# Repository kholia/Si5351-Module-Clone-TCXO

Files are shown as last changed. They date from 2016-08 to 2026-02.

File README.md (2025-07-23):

#### Notes

Note: We are using KiCad 7.0.x version to build this project.

[UPDATE] The design was validated on 27th-Feb-2023. It works really well for
WSPR @ 28 MHz where the original Adafruit Si5351 module is barely usable.

#### JLC PCBA files

- [Gerbers](./Adafruit-Si5351A-v3/jlcpcb/production_files/GERBER-Adafruit-Si5351A.zip)
- [BOM](./Adafruit-Si5351A-v3/jlcpcb/production_files/BOM-Adafruit-Si5351A.csv)
- [CPL](./Adafruit-Si5351A-v3/jlcpcb/production_files/CPL-Adafruit-Si5351A.csv)

#### PCB render

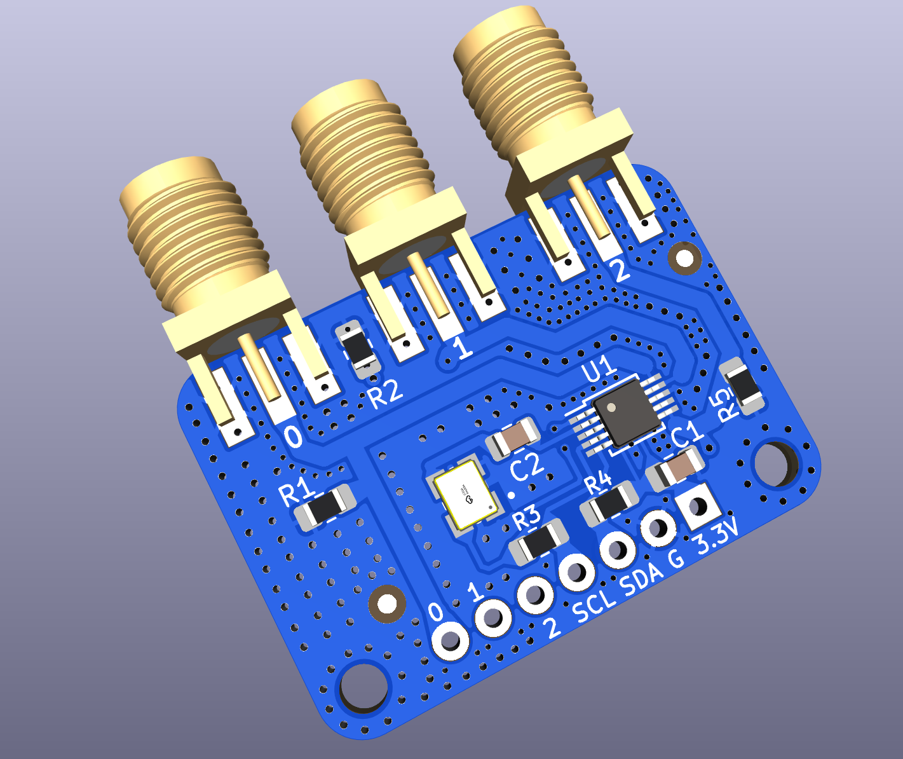
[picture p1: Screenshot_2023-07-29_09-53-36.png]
Render


#### BOM Sources

- https://www.lcsc.com/ - MS5351M

- https://www.comkey.in/ - SMD passives

- https://www.ktron.in/ - SMA connectors for cheap

- https://www.semikart.com/ - TCXOs

Note: International buyers can buy from DigiKey or Mouser.

#### Credits

- Sambhu Dharmadevan (VU3KQF)

- Dhiru Kholia (VU3CER)

#### Supported TCXO Modules

- [DEFAULT] KDS Daishinku 1XTW26000MAA (26 MHz)

- YXC Crystal Oscillators OW2EL89CENUXK7YLC-25M

- huaxindianzi 3T025000VX - 25 MHz

- Jauch Quartz O 25,0-JT32C-A-K-3,3-LF

- Abracon ASTX-H11-25.000MHZ-T

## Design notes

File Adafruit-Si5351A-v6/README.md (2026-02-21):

This version is ready for JLCPCB's PCBA process. Enjoy! ;)

This project uses KiCad 9.0.

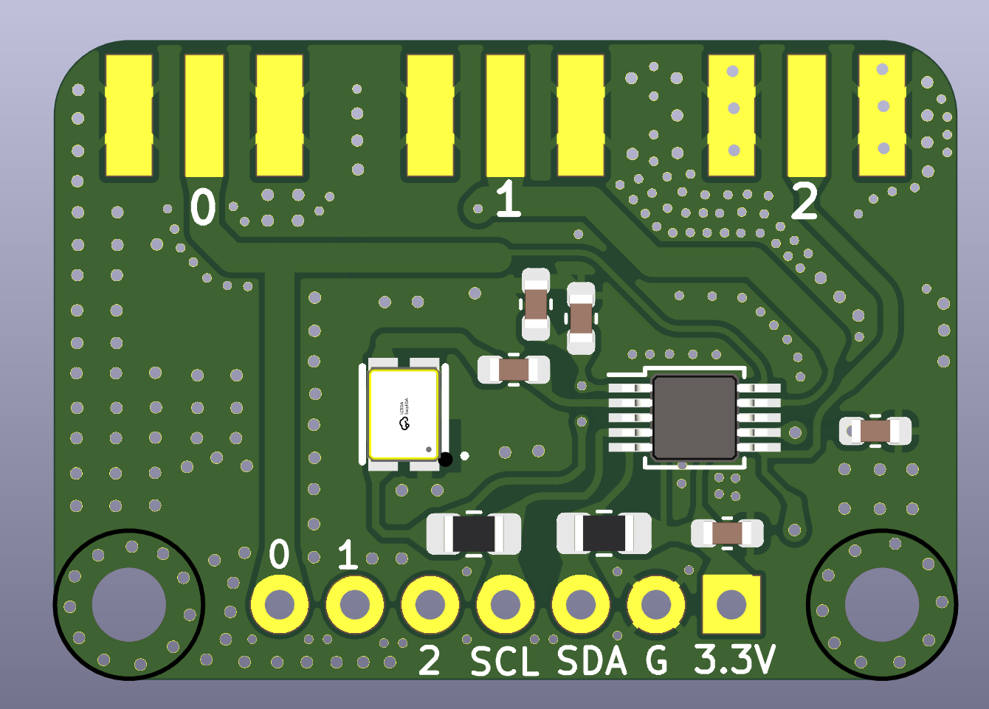
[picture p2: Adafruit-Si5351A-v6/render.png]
3D Render


Update (Feb-2026): These `Adafruit-Si5351A-v6` PCBs were assembled by JLCPCB and they work great!

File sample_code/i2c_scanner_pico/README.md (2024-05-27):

Si5351 chip will respond on the I2C bus even if it isn't connected to a clock
signal source (crystal / oscillator).

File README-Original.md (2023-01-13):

## Adafruit Si5351A Clock Generator Breakout PCB
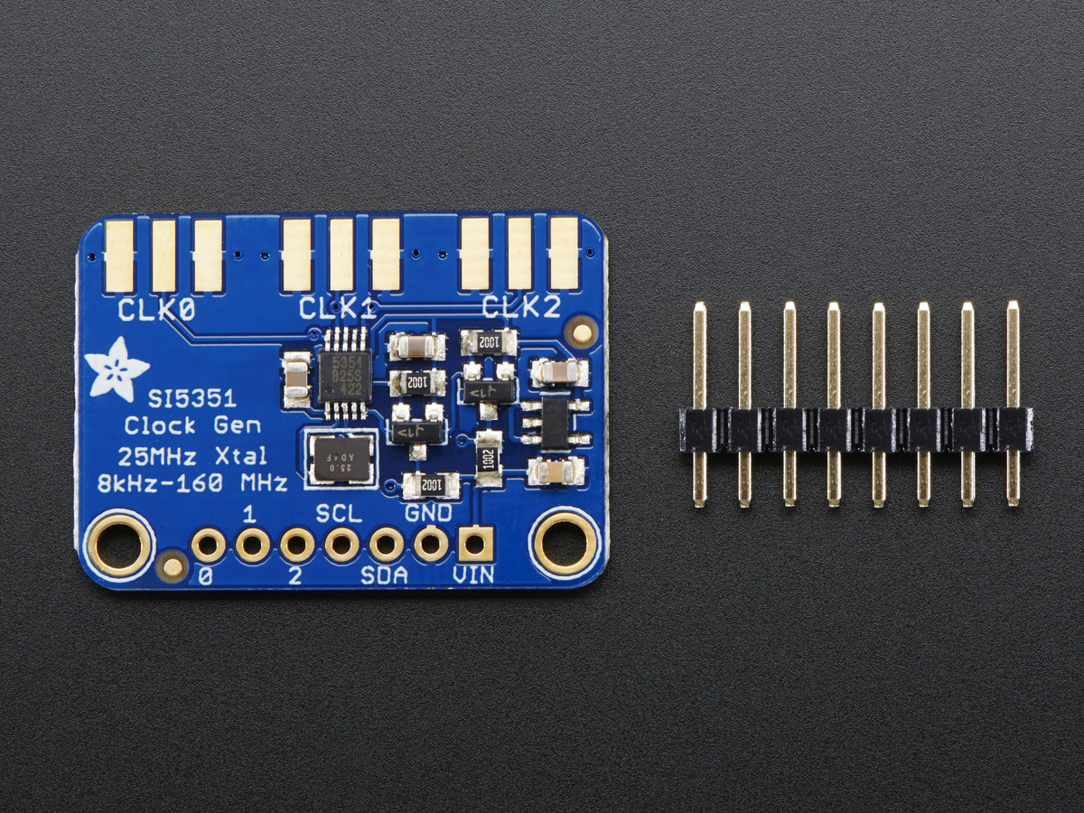
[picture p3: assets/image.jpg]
<a href="http://www.adafruit.com/products/2045"><br/>
Click here to purchase one from the Adafruit shop</a>

Never hunt around for another crystal again, with the Si5351A clock generator breakout from Adafruit! This chip has a precision 25MHz crystal reference and internal PLL and dividers so it can generate just about any frequency, from <8KHz up to 150+ MHz.

The Si5351A clock generator is an I2C controller clock generator. It uses the onboard precision clock to drive multiple PLL's and clock dividers using I2C instructions. By setting up the PLL and dividers you can create precise and arbitrary frequencies. There are three independent outputs, and each one can have a different frequency. Outputs are 3Vpp, either through a breadboard-friendly header or, for RF work, an optional SMA connector.

We put this handy little chip onto it's own breakout board PCB, with a 3.3V LDO regulator so it can be powered from 3-5VDC. We also put level shifting circuitry on the I2C lines so you can use this chip safely with 3V or 5V logic.

PCB files for the Adafruit Si5351A Clock Generator Breakout. The format is EagleCAD schematic and board layout
- http://www.adafruit.com/product/2045

### License

Adafruit invests time and resources providing this open source design, please support Adafruit and open-source hardware by purchasing products from [Adafruit](https://www.adafruit.com)!

All text above must be included in any redistribution

Designed by Limor Fried/Ladyada for Adafruit Industries.
Creative Commons Attribution/Share-Alike, all text above must be included in any redistribution.
See license.txt for additional information.

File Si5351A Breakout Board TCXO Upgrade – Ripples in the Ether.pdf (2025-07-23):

nt7s.com (https://nt7s.com/2016/04/si5351a-breakout-board-tcxo-upgrade/)

## Si5351A Breakout Board TCXO Upgrade – Ripples in the Ether

~3 minutes

Skip to content

I’m pleased to announce an upgrade to the Etherkit Si5351A Breakout Board with TCXO reference oscillator. In boards
manufactured previous to today (and the ones kitted in the initial crowdfunded initiative), the TCXO used was a Fox FOX924B-25.000. It worked well and did the job it was supposed to, but has one flaw in certain situations. The compensation loop in this particular TCXO has relatively wide frequency adjustment steps that can become obvious when using the Si5351A Breakout Board in a very narrow band mode such as QRSS. Here is a screen capture from Argo showing the behavior of the Si5351A Breakout Board with the Fox TCXO when outputting a carrier on 28 MHz, from a cold start.

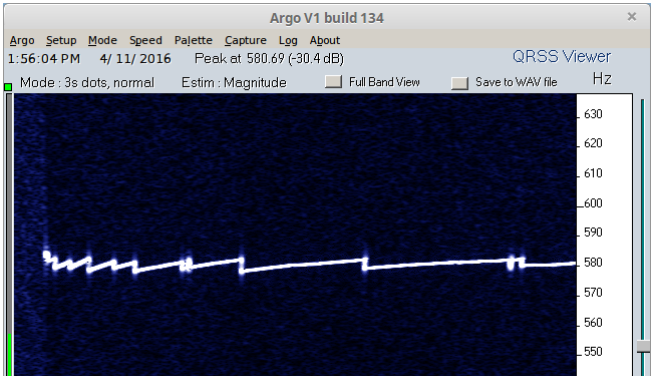
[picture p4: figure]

Fox FOX925B-25.000

As you can see, as the TCXO is stabilizing to operating temperature, the compensation circuit adjusts the frequency in relative course steps of around 3 Hz or so. Once the TCXO is warmed up, it jumps around less often, but still does occasionally have to frequency correct, and does so in a jump of similar size. This TCXO is still fine for most other uses, such as a VFO for a SSB/CW radio, but doesn’t work so great for the MEPT modes, especially on the upper frequency range of the Si5351.

In the course of developing OpenBeacon 2, I determined that I would need to find a more suitable TCXO to use with the Si5351. After trying about five different oscillators, I finally found a fantastic substitute, and it only costs a bit more than the Fox TCXO. The Abracon ASTX-H11-25.000MHZ-T comes in a smaller package than the
Fox FOX924B-25.000, but it will still fit on the footprint for X1 on the Si5351A Breakout Board. Here you can see the same test as above run for the Abracon TCXO.

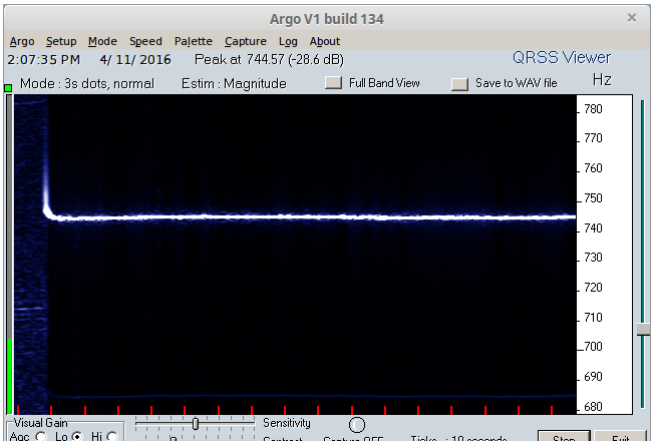
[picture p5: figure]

Abracon ASTX-H11-25.000M

It seems to find a stable frequency very quickly, and more importantly you can see that the compensation loop seems much tighter, with frequency corrections coming much faster and in smaller increments. You can only barely see a bit of fuzz from the frequency corrections on this low-bandwidth plot. This is much, much better for the MEPT modes.

As of today, all of the Si5351A Breakout Boards with TCXO option sold in the Etherkit store (https://www.etherkit.com/rf-modules/si5351a-breakout-board.html) will have the Abracon TCXO, and the price will stay the same at $15.

### Post navigation

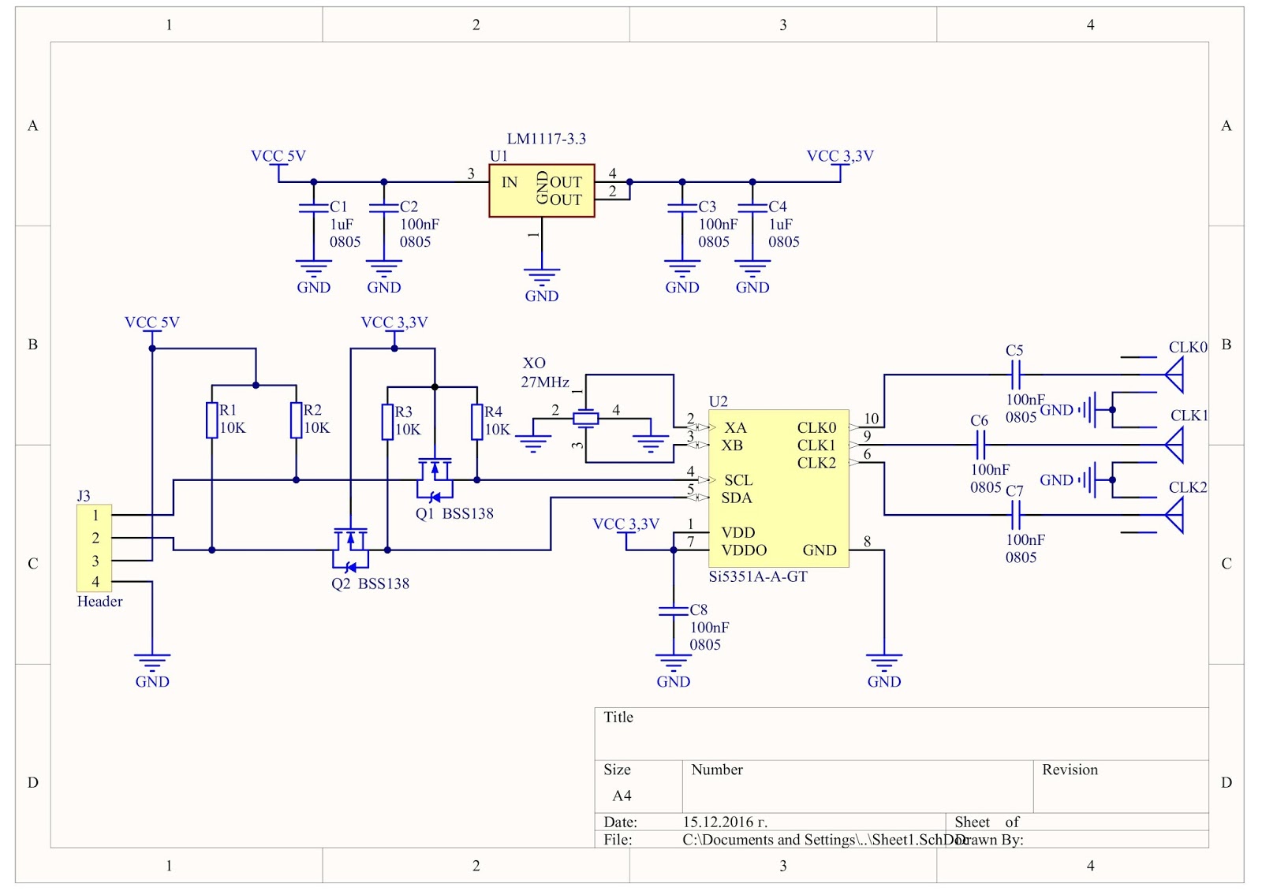
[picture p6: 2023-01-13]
datasheets/Schematic_Project1.jpg

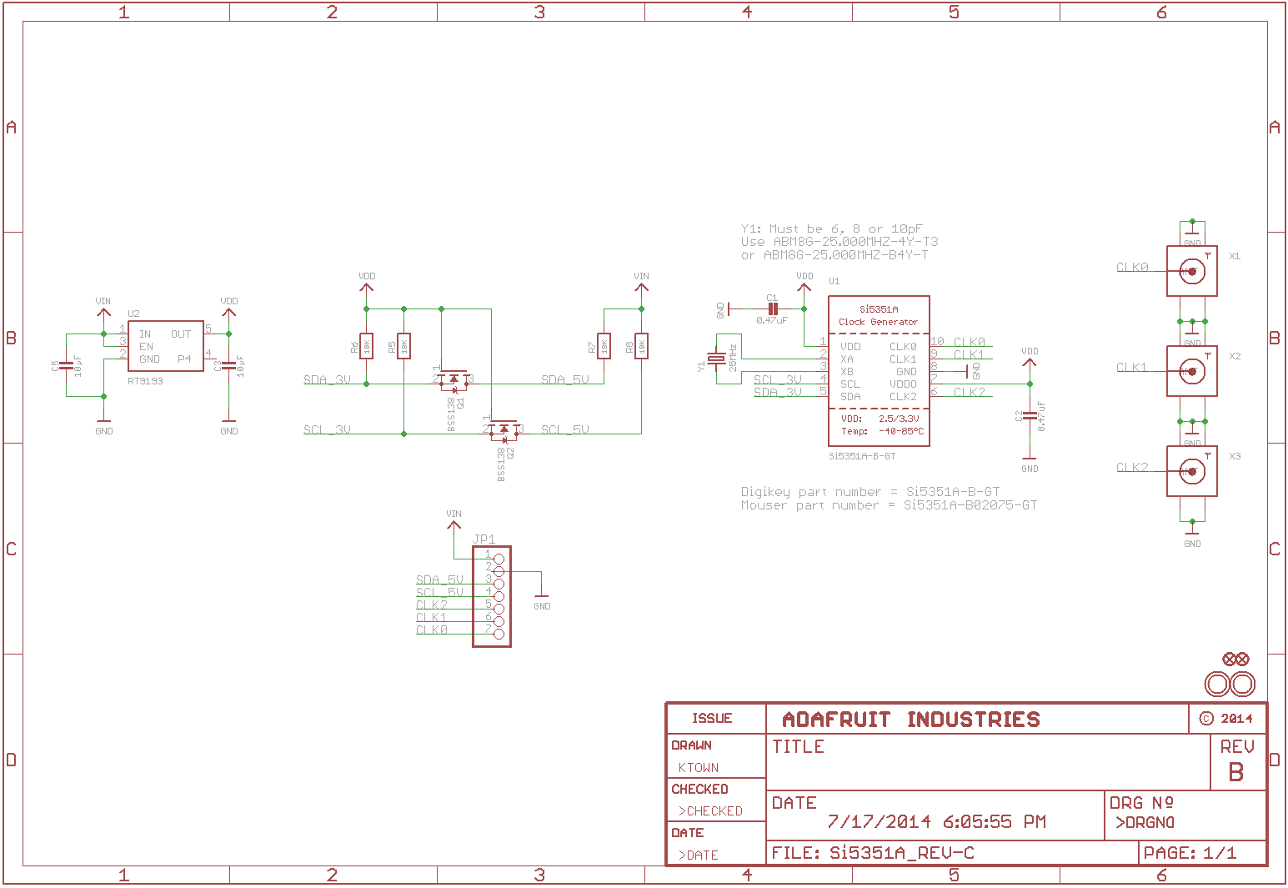
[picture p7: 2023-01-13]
adafruit_products_schem.png

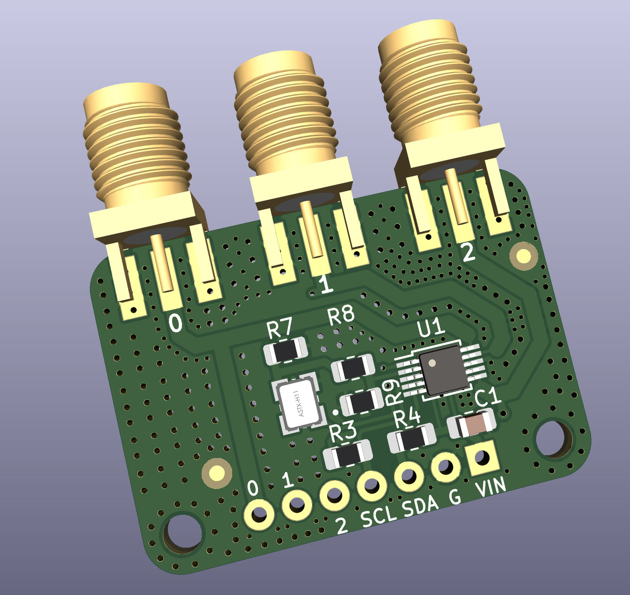
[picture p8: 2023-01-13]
Screenshot_2022-11-25_15-31-06.png

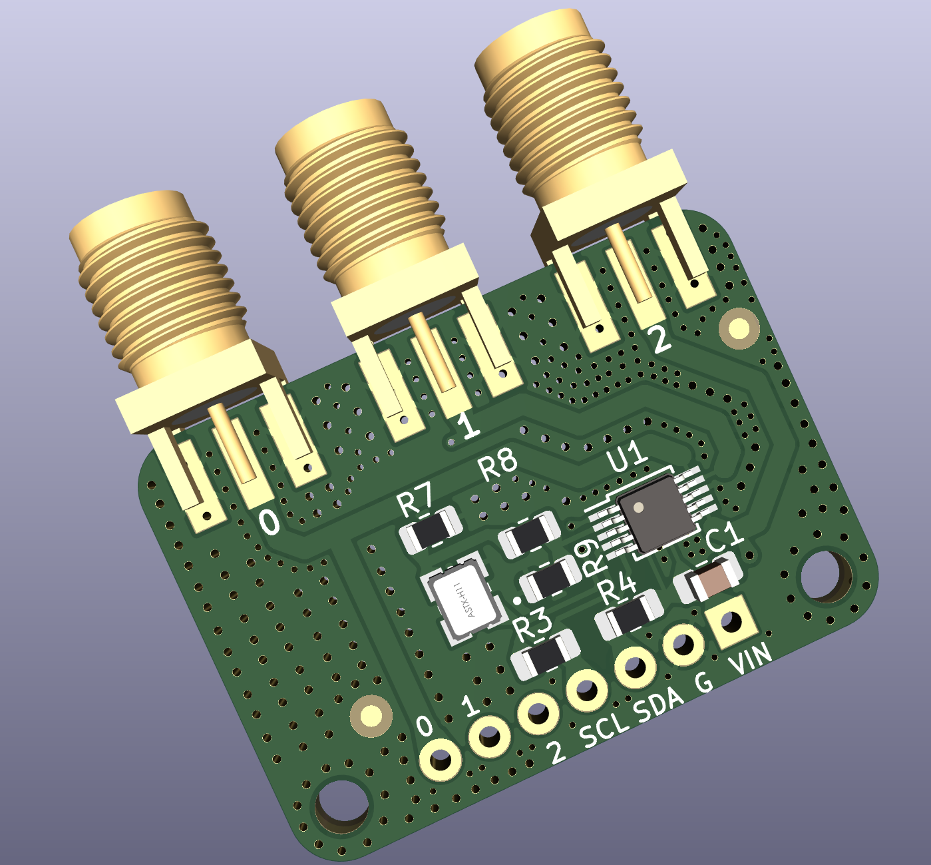
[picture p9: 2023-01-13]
Screenshot_2022-12-14_11-32-38.png

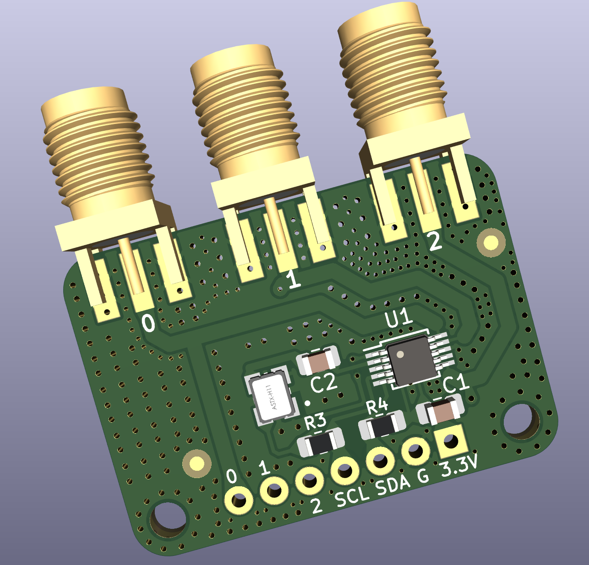
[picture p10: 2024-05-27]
Screenshot_2023-02-24_00-34-42-v2.png

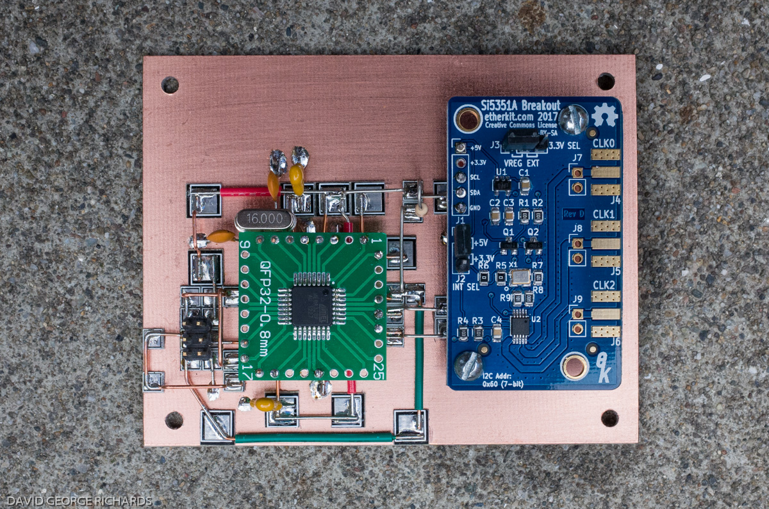
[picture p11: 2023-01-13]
datasheets/original.jpg

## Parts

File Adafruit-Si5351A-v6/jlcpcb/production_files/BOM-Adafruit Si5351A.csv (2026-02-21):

Comment | Designator | Footprint | LCSC | Quantity
104 | C1,C2,C4 | C_0603_1608Metric | C14663 | 3
105 | C3,C5 | C_0603_1608Metric | C15849 | 2
1k | R3,R4 | R_0805_2012Metric_Pad1.20x1.40mm_HandSolder | C17513 | 2
OSCILLATOR | Y1 | OSC-SMD_4P-L3.2-W2.5-BL_1XTV | C48888230 | 1
SI5351A | U1 | MSOP-10_3x3mm_P0.5mm | C1509083 | 1

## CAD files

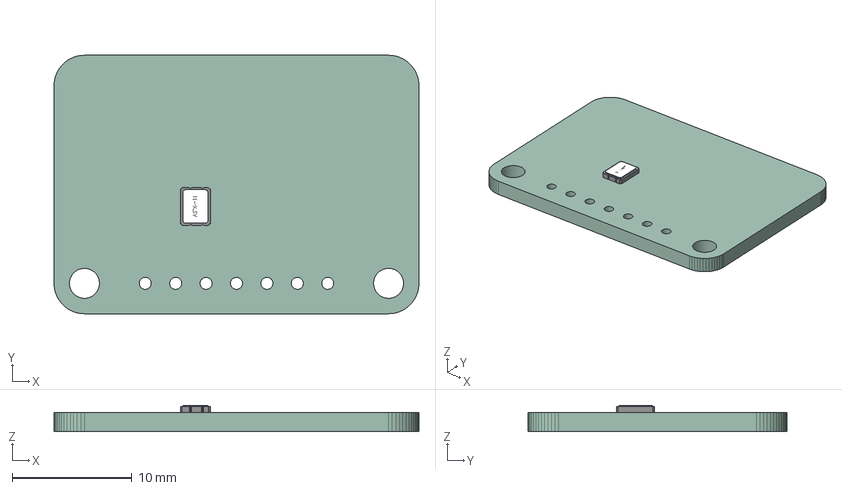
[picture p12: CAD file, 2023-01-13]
Adafruit Si5351A-v2/Adafruit Si5351A Plain.step
30.5 x 21.6 x 2.20 mm
PCB

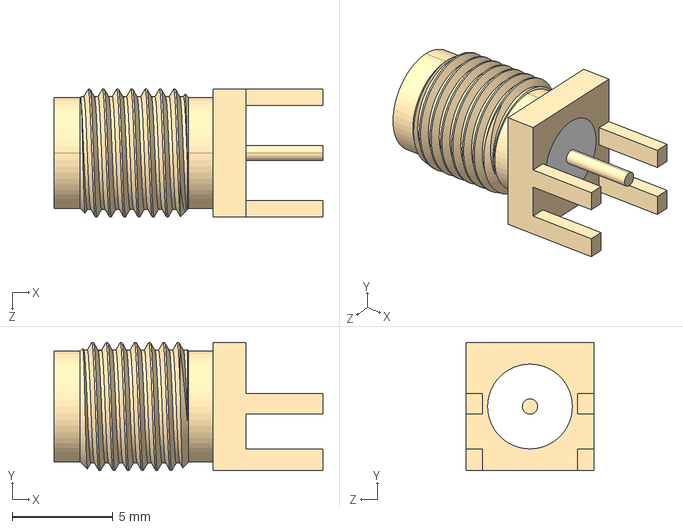
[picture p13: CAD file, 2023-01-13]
Adafruit-Si5351A-v6/models/CON-SMA-EDGE-S--3DModel-STEP-56544.STEP
13.3 x 6.35 x 6.35 mm

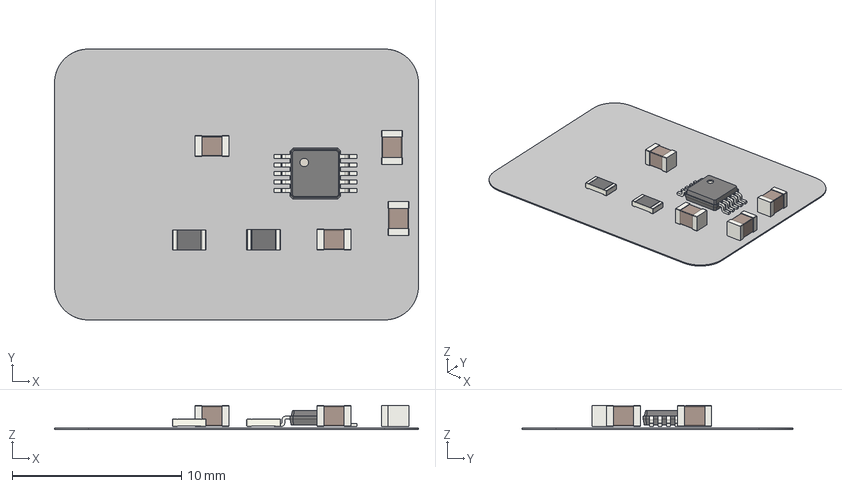
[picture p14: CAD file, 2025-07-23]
Si5351-Trimmed-Module-25-MHz/Si5351-Trimmed.step
21.5 x 16.0 x 1.43 mm
C_0805_2012Metric x 4
R_0805_2012Metric x 2
OSC-SMD_4P-L3.2-W2.5-H1.0
MSOP-10_3x3mm_P0.5mm
Adafruit Si5351A_silkscreen
Adafruit Si5351A_soldermask
Adafruit Si5351A_PCB

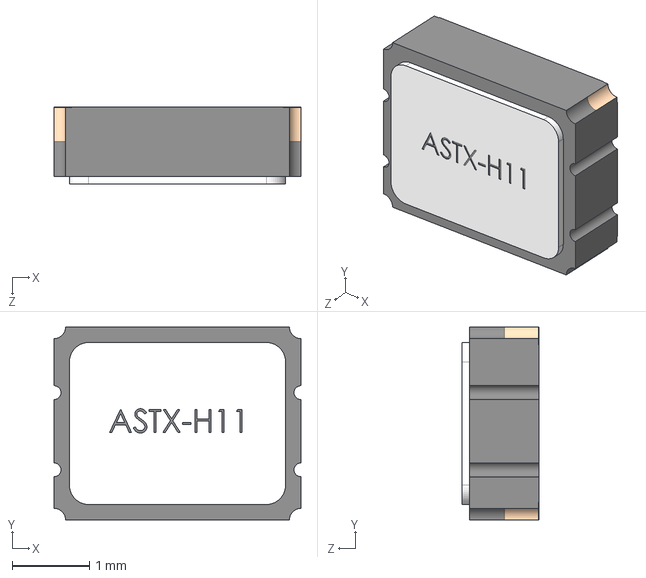
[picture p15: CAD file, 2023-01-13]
Adafruit-Si5351A-v6/models/ASTX-H11-25.000MHZ-T.step
3.20 x 2.50 x 1.00 mm

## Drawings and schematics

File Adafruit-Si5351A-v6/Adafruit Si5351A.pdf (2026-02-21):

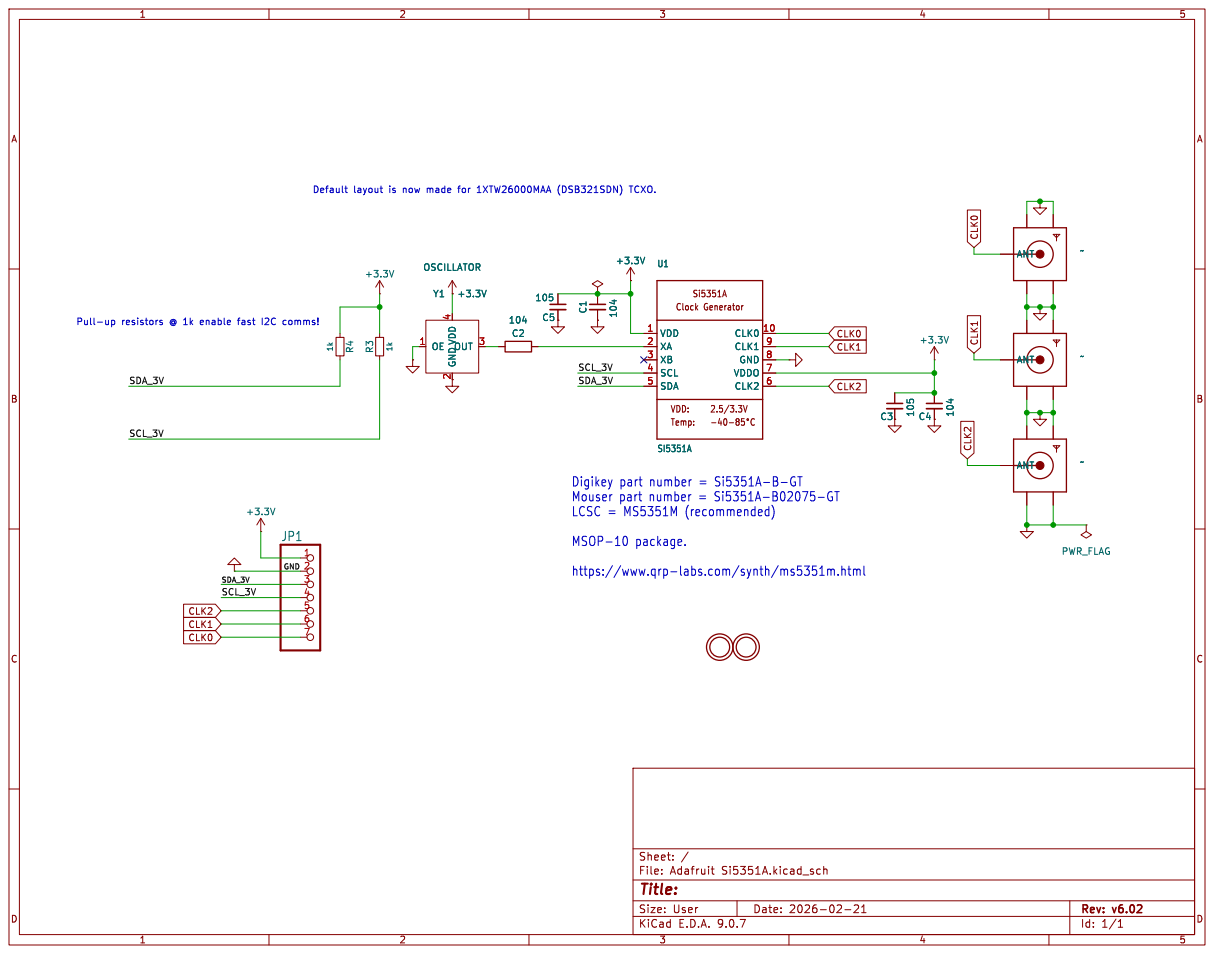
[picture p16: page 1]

https://www.qrp-labs.com/synth/ms5351m.html +3.3V

VDD: Temp:Si5351A Clock Generator 2.5/3.3V

Id: 1/1 Title: File: Adafruit Si5351A.kicad_sch Sheet: /

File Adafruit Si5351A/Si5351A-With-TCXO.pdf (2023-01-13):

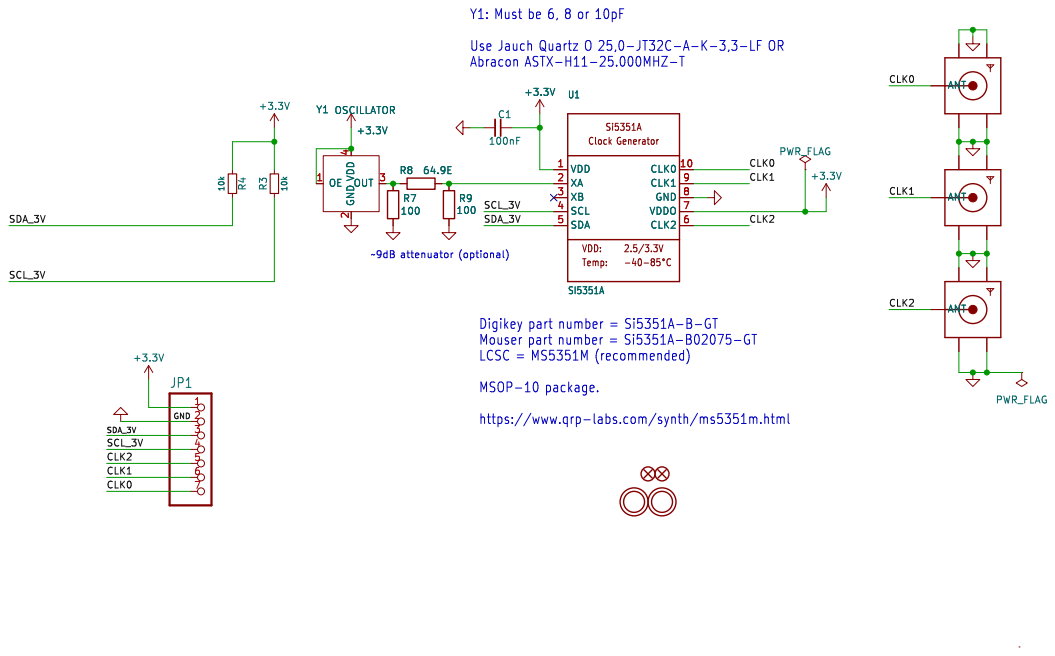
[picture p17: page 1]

Use Jauch Quartz O 25,0-JT32C-A-K-3,3-LF OR
Abracon ASTX-H11-25.000MHZ-T

Digikey part number = Si5351A-B-GT
Mouser part number = Si5351A-B02075-GT
LCSC = MS5351M (recommended)

https://www.qrp-labs.com/synth/ms5351m.html

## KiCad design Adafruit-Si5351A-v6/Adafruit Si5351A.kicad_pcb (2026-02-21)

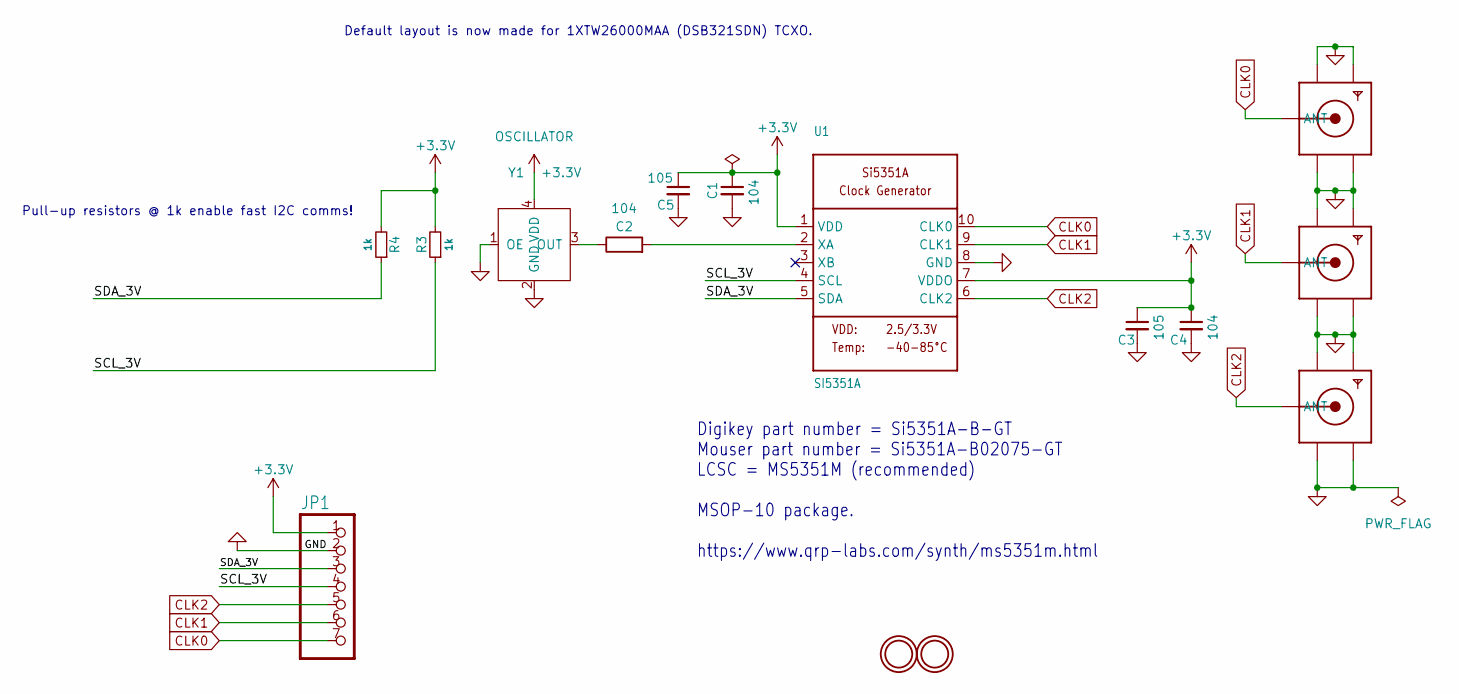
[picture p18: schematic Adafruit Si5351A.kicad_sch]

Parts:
C1, C2, C4: 104; C_0603_1608Metric
C3, C5: 105; C_0603_1608Metric
H1, H2: MOUNTINGHOLE2.5; MountingHole_2.5mm
JP1: 1X07_ROUND_76
R3, R4: 1k; R_0805_2012Metric_Pad1.20x1.40mm_HandSolder
U1: SI5351A; MSOP-10_3x3mm_P0.5mm
X1, X2, X3: SMA_EDGELAUNCH
Y1: OSCILLATOR; OSC-SMD_4P-L3.2-W2.5-BL_1XTV

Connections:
+3.3V: C1.1, C3.1, C4.1, C5.1, JP1.1, R3.2, R4.2, U1.1 (VDD), U1.7 (VDDO), Y1.4 (VDD)
/SCL_3V: JP1.4, R3.1, U1.4 (SCL)
/SDA_3V: JP1.3, R4.1, U1.5 (SDA)
CLK0: JP1.7, U1.10 (CLK0), X1.P (ANT)
CLK1: JP1.6, U1.9 (CLK1), X2.P (ANT)
CLK2: JP1.5, U1.6 (CLK2), X3.P (ANT)
GND: C1.2, C3.2, C4.2, C5.2, JP1.2, U1.8 (GND), X1.GND@1 (GND4), X1.GND@2 (GND3), X1.GND@3 (GND2), X1.GND@4 (GND1), X2.GND@1 (GND4), X2.GND@2 (GND3), X2.GND@3 (GND2), X2.GND@4 (GND1), X3.GND@1 (GND4), X3.GND@2 (GND3), X3.GND@3 (GND2), X3.GND@4 (GND1), Y1.1 (OE), Y1.2 (GND)
unnamed: C2.2, U1.2 (XA)
unnamed: C2.1, Y1.3 (OUT)

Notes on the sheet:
Default layout is now made for 1XTW26000MAA (DSB321SDN) TCXO.
Pull-up resistors @ 1k enable fast I2C comms!
Digikey part number = Si5351A-B-GT Mouser part number = Si5351A-B02075-GT LCSC = MS5351M (recommended) MSOP-10 package. https://www.qrp-labs.com/synth/ms5351m.html

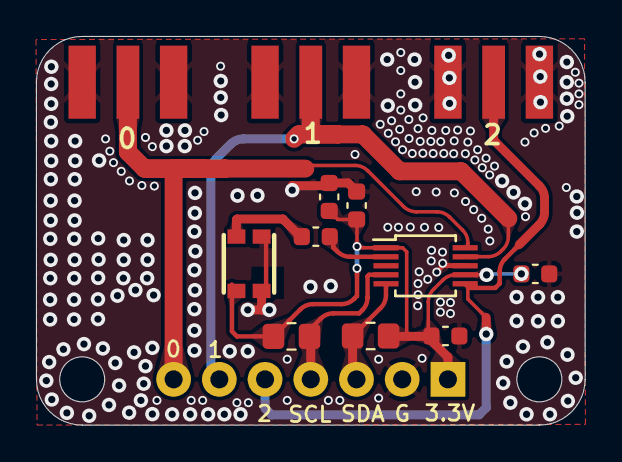
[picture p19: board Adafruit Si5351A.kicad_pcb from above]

Board: 2 copper layers, 30.5 x 21.6 mm, 15 parts (0 on the bottom side), 9 nets.

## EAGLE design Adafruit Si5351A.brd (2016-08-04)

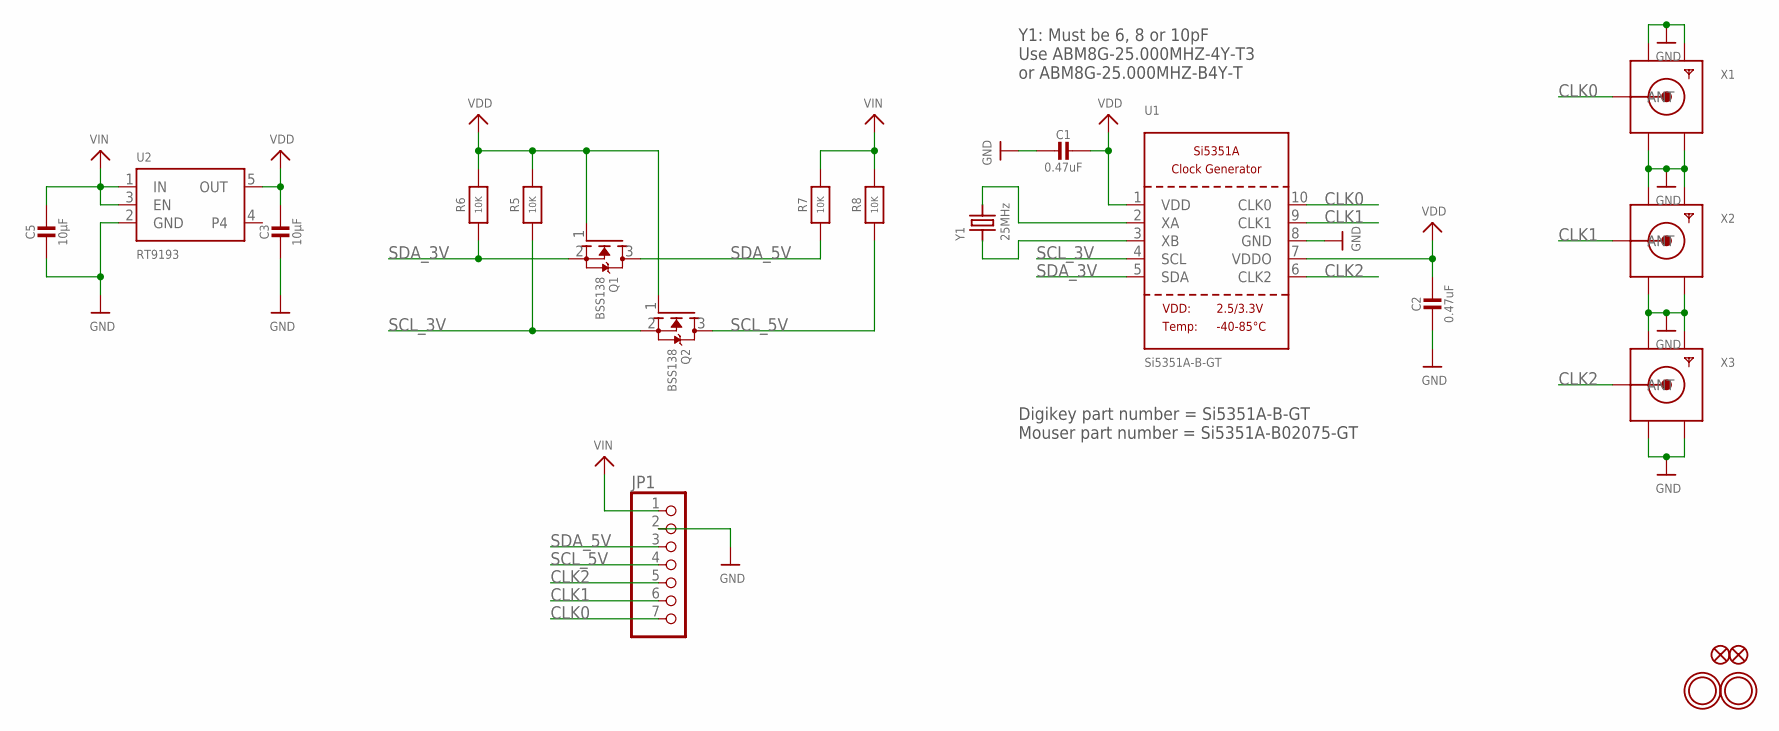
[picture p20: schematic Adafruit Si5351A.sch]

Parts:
C1, C2: 0.47uF; 0805-NO
C3, C5: 10µF; 0805-NO
FID1, FID2: FIDUCIAL""; FIDUCIAL_1MM
JP1: HEADER-1X7THICKER; 1X07_ROUND_76
Q1, Q2: BSS138; SOT23-WIDE
R5, R6, R7, R8: 10K; 0805-NO
U1: Si5351A-B-GT; MSOP10
U2: RT9193; SOT23-5
U$10, U$11: MOUNTINGHOLE2.5; MOUNTINGHOLE_2.5_PLATED
X1, X2, X3: SMACONNECTOR_EDGE; SMA_EDGELAUNCH
Y1: 25MHz; CRYSTAL_3.2X2.5

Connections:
CLK0: JP1.7, U1.10 (CLK0), X1.P (ANT)
CLK1: JP1.6, U1.9 (CLK1), X2.P (ANT)
CLK2: JP1.5, U1.6 (CLK2), X3.P (ANT)
GND: C1.2, C2.2, C3.2, C5.2, JP1.2, U1.8 (GND), U2.2 (GND), X1.GND@1 (GND4), X1.GND@2 (GND3), X1.GND@3 (GND2), X1.GND@4 (GND1), X2.GND@1 (GND4), X2.GND@2 (GND3), X2.GND@3 (GND2), X2.GND@4 (GND1), X3.GND@1 (GND4), X3.GND@2 (GND3), X3.GND@3 (GND2), X3.GND@4 (GND1)
unnamed: U1.3 (XB), Y1.1
unnamed: U1.2 (XA), Y1.2
SCL_3V: Q2.2 (S), R5.1, U1.4 (SCL)
SCL_5V: JP1.4, Q2.3 (D), R8.1
SDA_3V: Q1.2 (S), R6.1, U1.5 (SDA)
SDA_5V: JP1.3, Q1.3 (D), R7.1
VDD: C1.1, C2.1, C3.1, Q1.1 (G), Q2.1 (G), R5.2, R6.2, U1.1 (VDD), U1.7 (VDDO), U2.5 (OUT)
VIN: C5.1, JP1.1, R7.2, R8.2, U2.1 (IN), U2.3 (EN)

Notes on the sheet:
Digikey part number = Si5351A-B-GT Mouser part number = Si5351A-B02075-GT
Y1: Must be 6, 8 or 10pF Use ABM8G-25.000MHZ-4Y-T3 or ABM8G-25.000MHZ-B4Y-T

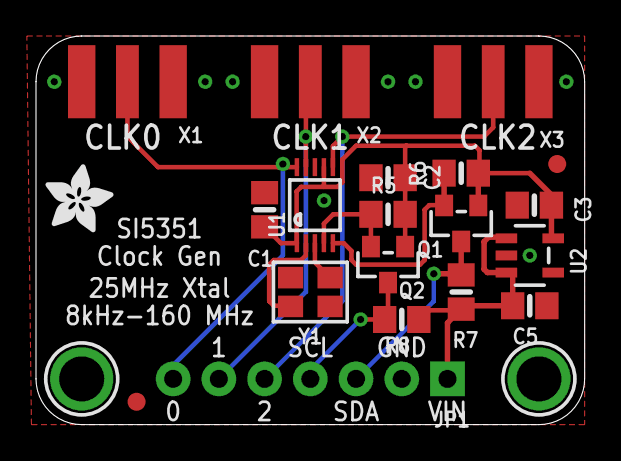
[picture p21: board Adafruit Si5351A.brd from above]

Board: 2 copper layers, 30.5 x 21.6 mm, 23 parts (1 on the bottom side), 12 nets.

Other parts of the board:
U$12: ADAFRUIT_3.5MM
U$23: ADAFRUIT_TEXT_20MM

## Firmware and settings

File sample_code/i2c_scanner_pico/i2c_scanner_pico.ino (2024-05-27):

// --------------------------------------
// i2c_scanner
//
// Version 1
//    This program (or code that looks like it)
//    can be found in many places.
//    For example on the Arduino.cc forum.
//    The original author is not know.
// Version 2, Juni 2012, Using Arduino 1.0.1
//     Adapted to be as simple as possible by Arduino.cc user Krodal
// Version 3, Feb 26  2013
//    V3 by louarnold
// Version 4, March 3, 2013, Using Arduino 1.0.3
//    by Arduino.cc user Krodal.
//    Changes by louarnold removed.
//    Scanning addresses changed from 0...127 to 1...119,
//    according to the i2c scanner by Nick Gammon
//    https://www.gammon.com.au/forum/?id=10896
// Version 5, March 28, 2013
//    As version 4, but address scans now to 127.
//    A sensor seems to use address 120.
// Version 6, November 27, 2015.
//    Added waiting for the Leonardo serial communication.
//
//
// This sketch tests the standard 7-bit addresses
// Devices with higher bit address might not be seen properly.
//

#include <Wire.h>


void setup()
{
  // Pico specific code
  Wire.setSDA(16);
  Wire.setSCL(17);

  Wire.begin();

  Serial.begin(115200);
  while (!Serial);             // Leonardo: wait for serial monitor

  delay(5000);
  Serial.println("\nI2C Scanner");
}


void loop()
{
  byte error, address;
  int nDevices;

  Serial.println("Scanning...");

  nDevices = 0;
  for (address = 1; address < 127; address++ )
  {
    // The i2c_scanner uses the return value of
    // the Write.endTransmisstion to see if
    // a device did acknowledge to the address.
    Wire.beginTransmission(address);
    error = Wire.endTransmission();

    if (error == 0)
    {
      Serial.print("I2C device found at address 0x");
      if (address < 16)
        Serial.print("0");
      Serial.print(address, HEX);
      Serial.println("  !");

      nDevices++;
    }
    else if (error == 4)
    {
      Serial.print("Unknown error at address 0x");
      if (address < 16)
        Serial.print("0");
      Serial.println(address, HEX);
    }
  }
  if (nDevices == 0)
    Serial.println("No I2C devices found\n");
  else
    Serial.println("done\n");

  delay(5000);           // wait 5 seconds for next scan
}

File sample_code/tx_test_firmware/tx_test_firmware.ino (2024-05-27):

#include <si5351.h>
#include "Wire.h"
#include <EEPROM.h>

#define RX 18 // RX SWITCH (GP18)

Si5351 si5351;

int cal_factor = 0;

// Debug helper
void led_flash()
{
  digitalWrite(LED_BUILTIN, HIGH);
  delay(250);
  digitalWrite(LED_BUILTIN, LOW);
  delay(250);
  digitalWrite(LED_BUILTIN, HIGH);
  delay(250);
  digitalWrite(LED_BUILTIN, LOW);
  delay(250);
  digitalWrite(LED_BUILTIN, HIGH);
  delay(250);
  digitalWrite(LED_BUILTIN, LOW);
}

void setup()
{
  int ret;

  pinMode(RX, OUTPUT);
  pinMode(LED_BUILTIN, OUTPUT);
  digitalWrite(RX, 0); // Turn off RX
  Serial.begin(115200);

  // I2C pins
  Wire.setSDA(16);
  Wire.setSCL(17);
  Wire.begin();

  // Initialize the Si5351
  ret = si5351.init(SI5351_CRYSTAL_LOAD_8PF, 26000000, cal_factor);
  if (ret != true) {
    led_flash();
    watchdog_reboot(0, 0, 1000);
  }

  si5351.set_freq(18074000 * 100ULL, SI5351_CLK0);
  si5351.output_enable(SI5351_CLK0, 1);

  si5351.set_freq(19074000 * 100ULL, SI5351_CLK1);
  si5351.output_enable(SI5351_CLK1, 1);

  si5351.set_freq(20074000 * 100ULL, SI5351_CLK2);
  si5351.output_enable(SI5351_CLK2, 1);

  // TIP: Monitor these frequencies using an adajacent SDR
}

void loop()
{
  delay(100);
}

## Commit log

2023-01-13 Native TCXO support
    Also add experimental support for 'KDS Daishinku 1XTW26000MAA' TCXO.
    [ASTX-H11-25.000MHZ-T.step, Adafruit Si5351A Plain.step, Adafruit Si5351A.kicad_pcb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]
2024-05-27 KDS Daishinku 1XTW26000MAA TCXO is default now
    [ASTX-H11-25.000MHZ-T.step, Adafruit Si5351A Plain.step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]
2025-04-17 More compliant product
    [ASTX-H11-25.000MHZ-T.step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]
2025-07-23 Make 'Si5351-Trimmed-Module*' public
    [ASTX-H11-25.000MHZ-T.step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]

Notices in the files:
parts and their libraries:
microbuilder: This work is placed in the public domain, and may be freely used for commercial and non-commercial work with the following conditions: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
